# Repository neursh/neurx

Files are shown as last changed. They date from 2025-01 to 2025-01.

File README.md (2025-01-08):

# Neurx

A mechanical keyboard aiming for maximum customizability.

## Features (WIP)

- A 75% keyboard (with numpad mode can be toggled).
- 4 programmable keys + 1 knob.
- Firmware is compatible with Raspberry Pi Pico (and Pico W), written in Rust.
- Plug and play, no driver needed, with 1000Hz polling rate.
- Software for Windows, provides better control over programmable keys.

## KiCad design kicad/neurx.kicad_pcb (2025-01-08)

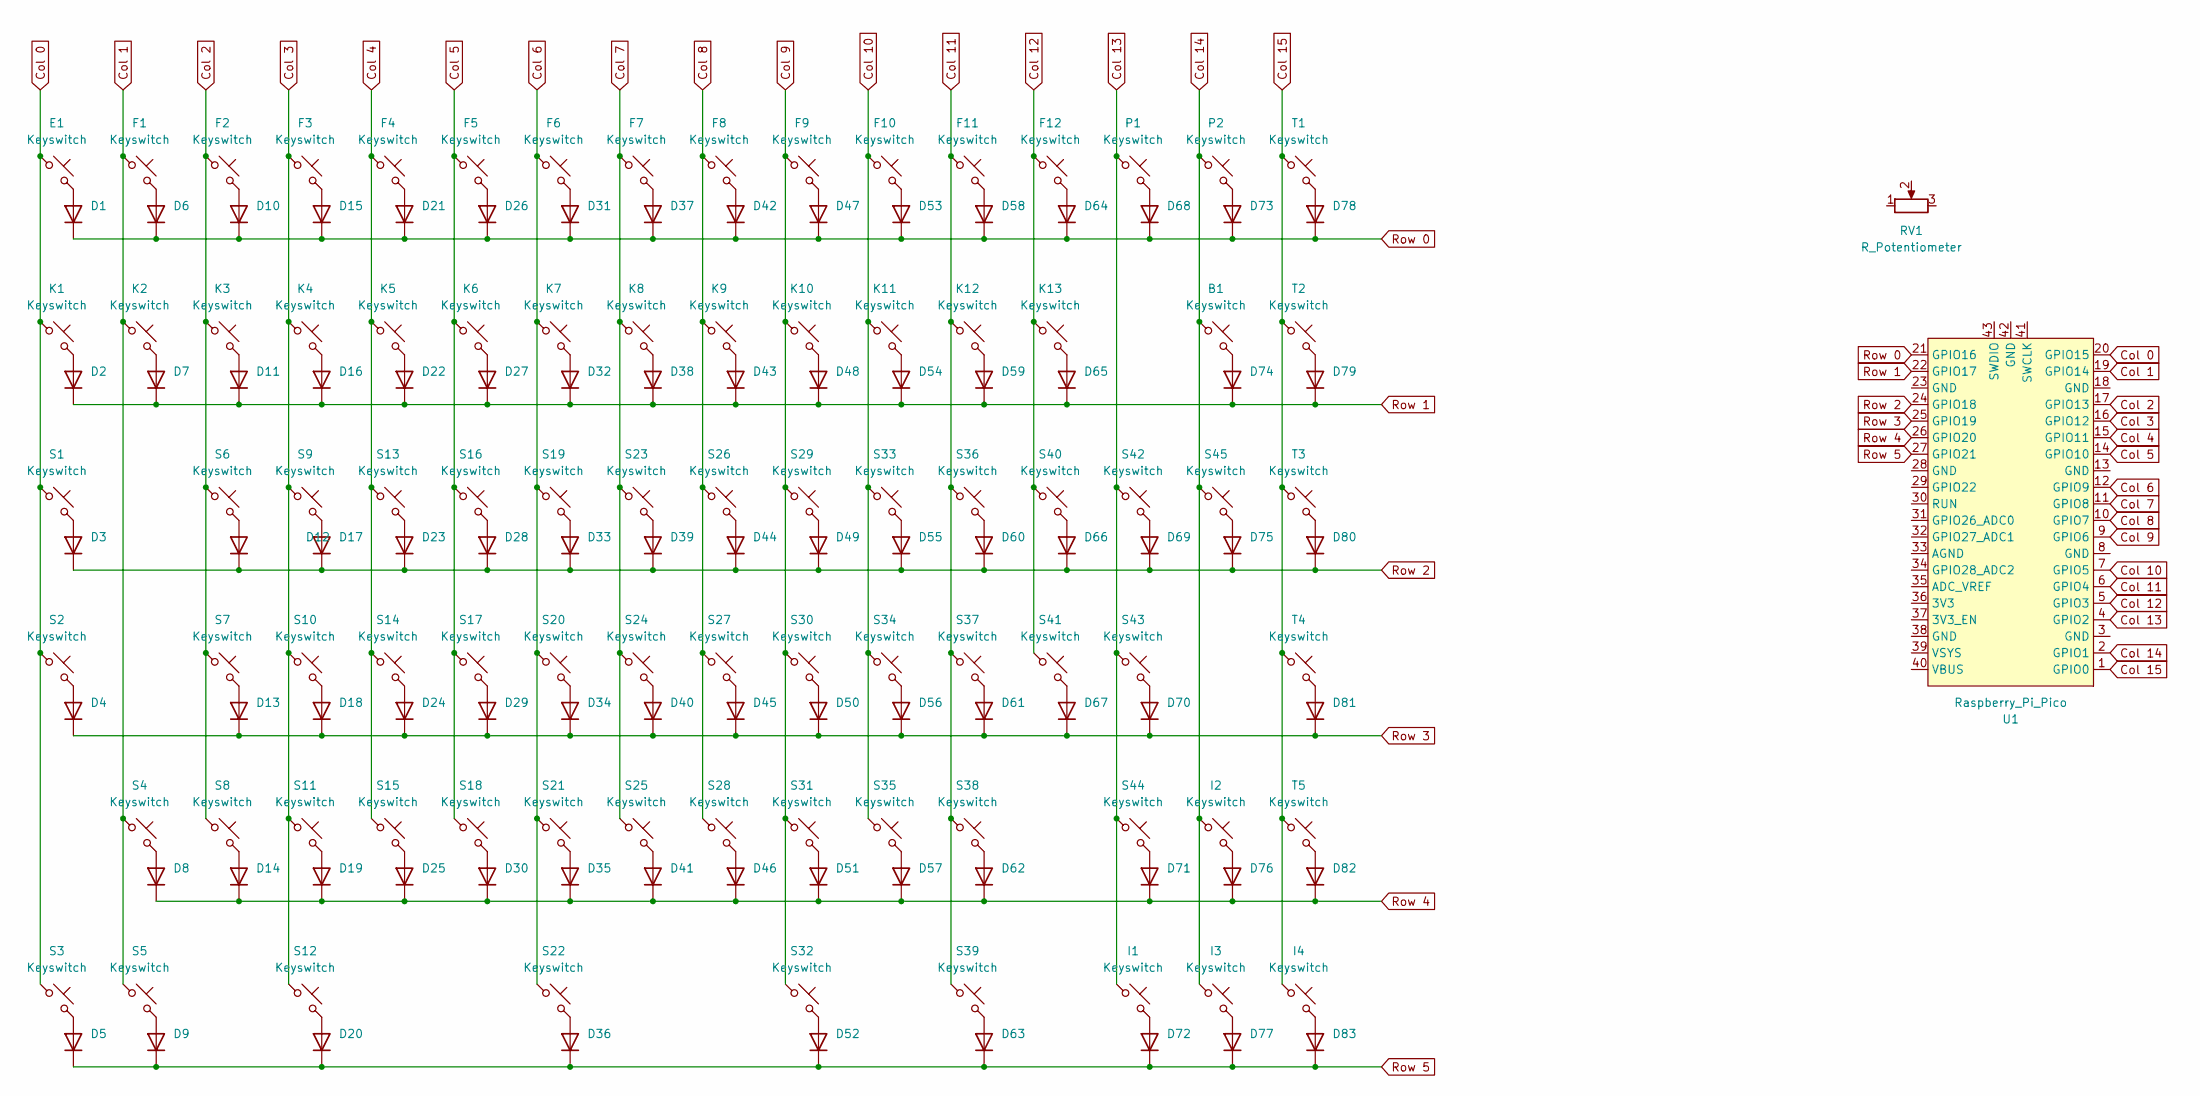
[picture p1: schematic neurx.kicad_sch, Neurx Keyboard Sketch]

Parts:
B1: Keyswitch; MX_PCB_2.00u
D1, D2, D3, D4, D5, D6, D7, D8, D9, D10, D11, D12, D13, D14, D15, D16, D17, D18, D19, D20, D21, D22, D23, D24, D25, D26, D27, D28, D29, D30, D31, D32, D33, D34, D35, D36, D37, D38, D39, D40, D41, D42, D43, D44, D45, D46, D47, D48, D49, D50, D51, D52, D53, D54, D55, D56, D57, D58, D59, D60, D61, D62, D63, D64, D65, D66, D67, D68, D69, D70, D71, D72, D73, D74, D75, D76, D77, D78, D79, D80, D81, D82, D83: Diode; Diode_DO-35
E1: Keyswitch; MX_PCB_1.00u
F1, F2, F3, F4, F5, F6, F7, F8, F9, F10, F11, F12: Keyswitch; MX_PCB_1.00u
I1, I2, I3, I4: Keyswitch; MX_PCB_1.00u
K1, K2, K3, K4, K5, K6, K7, K8, K9, K10, K11, K12, K13: Keyswitch; MX_PCB_1.00u
P1, P2: Keyswitch; MX_PCB_1.00u
RV1: R_Potentiometer
S1, S45: Keyswitch; MX_PCB_1.50u
S2, S44: Keyswitch; MX_PCB_1.75u
S3, S5, S12, S32, S39: Keyswitch; MX_PCB_1.25u
S4, S43: Keyswitch; MX_PCB_2.25u
S6, S7, S8, S9, S10, S11, S13, S14, S15, S16, S17, S18, S19, S20, S21, S23, S24, S25, S26, S27, S28, S29, S30, S31, S33, S34, S35, S36, S37, S38, S40, S41, S42: Keyswitch; MX_PCB_1.00u
S22: Keyswitch; MX_PCB_6.25u
T1, T2, T3, T4, T5: Keyswitch; MX_PCB_1.00u
U1: Raspberry_Pi_Pico

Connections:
Col 0: E1.1, K1.1, S1.1, S2.1, S3.1, U1.20 (GPIO15)
Col 1: F1.1, K2.1, S4.1, S5.1, U1.19 (GPIO14)
Col 2: F2.1, K3.1, S6.1, S7.1, S8.1, U1.17 (GPIO13)
Col 3: F3.1, K4.1, S9.1, S10.1, S11.1, S12.1, U1.16 (GPIO12)
Col 4: F4.1, K5.1, S13.1, S14.1, S15.1, U1.15 (GPIO11)
Col 5: F5.1, K6.1, S16.1, S17.1, S18.1, U1.14 (GPIO10)
Col 6: F6.1, K7.1, S19.1, S20.1, S21.1, S22.1, U1.12 (GPIO9)
Col 7: F7.1, K8.1, S23.1, S24.1, S25.1, U1.11 (GPIO8)
Col 8: F8.1, K9.1, S26.1, S27.1, S28.1, U1.10 (GPIO7)
Col 9: F9.1, K10.1, S29.1, S30.1, S31.1, S32.1, U1.9 (GPIO6)
Col 10: F10.1, K11.1, S33.1, S34.1, S35.1, U1.7 (GPIO5)
Col 11: F11.1, K12.1, S36.1, S37.1, S38.1, S39.1, U1.6 (GPIO4)
Col 12: F12.1, K13.1, S40.1, S41.1, U1.5 (GPIO3)
Col 13: I1.1, P1.1, S42.1, S43.1, S44.1, U1.4 (GPIO2)
Col 14: B1.1, I2.1, I3.1, P2.1, S45.1, U1.2 (GPIO1)
Col 15: I4.1, T1.1, T2.1, T3.1, T4.1, T5.1, U1.1 (GPIO0)
unnamed: D1.2 (A), E1.2
unnamed: D2.2 (A), K1.2
unnamed: D3.2 (A), S1.2
unnamed: D4.2 (A), S2.2
unnamed: D5.2 (A), S3.2
unnamed: D6.2 (A), F1.2
unnamed: D7.2 (A), K2.2
unnamed: D8.2 (A), S4.2
unnamed: D9.2 (A), S5.2
unnamed: D10.2 (A), F2.2
unnamed: D11.2 (A), K3.2
unnamed: D12.2 (A), S6.2
unnamed: D13.2 (A), S7.2
unnamed: D14.2 (A), S8.2
unnamed: D15.2 (A), F3.2
unnamed: D16.2 (A), K4.2
unnamed: D17.2 (A), S9.2
unnamed: D18.2 (A), S10.2
unnamed: D19.2 (A), S11.2
unnamed: D20.2 (A), S12.2
unnamed: D21.2 (A), F4.2
unnamed: D22.2 (A), K5.2
unnamed: D23.2 (A), S13.2
unnamed: D24.2 (A), S14.2
unnamed: D25.2 (A), S15.2
unnamed: D26.2 (A), F5.2
unnamed: D27.2 (A), K6.2
unnamed: D28.2 (A), S16.2
unnamed: D29.2 (A), S17.2
unnamed: D30.2 (A), S18.2
unnamed: D31.2 (A), F6.2
unnamed: D32.2 (A), K7.2
unnamed: D33.2 (A), S19.2
unnamed: D34.2 (A), S20.2
unnamed: D35.2 (A), S21.2
unnamed: D36.2 (A), S22.2
unnamed: D37.2 (A), F7.2
unnamed: D38.2 (A), K8.2
unnamed: D39.2 (A), S23.2
unnamed: D40.2 (A), S24.2
unnamed: D41.2 (A), S25.2
unnamed: D42.2 (A), F8.2
unnamed: D43.2 (A), K9.2
unnamed: D44.2 (A), S26.2
unnamed: D45.2 (A), S27.2
unnamed: D46.2 (A), S28.2
unnamed: D47.2 (A), F9.2
unnamed: D48.2 (A), K10.2
unnamed: D49.2 (A), S29.2
unnamed: D50.2 (A), S30.2
unnamed: D51.2 (A), S31.2
unnamed: D52.2 (A), S32.2
unnamed: D53.2 (A), F10.2
unnamed: D54.2 (A), K11.2
unnamed: D55.2 (A), S33.2
unnamed: D56.2 (A), S34.2
unnamed: D57.2 (A), S35.2
unnamed: D58.2 (A), F11.2
unnamed: D59.2 (A), K12.2
unnamed: D60.2 (A), S36.2
unnamed: D61.2 (A), S37.2
unnamed: D62.2 (A), S38.2
unnamed: D63.2 (A), S39.2
unnamed: D64.2 (A), F12.2
unnamed: D65.2 (A), K13.2
unnamed: D66.2 (A), S40.2
unnamed: D67.2 (A), S41.2
unnamed: D68.2 (A), P1.2
unnamed: D69.2 (A), S42.2
unnamed: D70.2 (A), S43.2
unnamed: D71.2 (A), S44.2
unnamed: D72.2 (A), I1.2
unnamed: D73.2 (A), P2.2
unnamed: B1.2, D74.2 (A)
unnamed: D75.2 (A), S45.2
unnamed: D76.2 (A), I2.2
unnamed: D77.2 (A), I3.2
unnamed: D78.2 (A), T1.2
unnamed: D79.2 (A), T2.2
unnamed: D80.2 (A), T3.2
unnamed: D81.2 (A), T4.2
unnamed: D82.2 (A), T5.2
unnamed: D83.2 (A), I4.2
Row 0: D1.1 (K), D6.1 (K), D10.1 (K), D15.1 (K), D21.1 (K), D26.1 (K), D31.1 (K), D37.1 (K), D42.1 (K), D47.1 (K), D53.1 (K), D58.1 (K), D64.1 (K), D68.1 (K), D73.1 (K), D78.1 (K), U1.21 (GPIO16)
Row 1: D2.1 (K), D7.1 (K), D11.1 (K), D16.1 (K), D22.1 (K), D27.1 (K), D32.1 (K), D38.1 (K), D43.1 (K), D48.1 (K), D54.1 (K), D59.1 (K), D65.1 (K), D74.1 (K), D79.1 (K), U1.22 (GPIO17)
Row 2: D3.1 (K), D12.1 (K), D17.1 (K), D23.1 (K), D28.1 (K), D33.1 (K), D39.1 (K), D44.1 (K), D49.1 (K), D55.1 (K), D60.1 (K), D66.1 (K), D69.1 (K), D75.1 (K), D80.1 (K), U1.24 (GPIO18)
Row 3: D4.1 (K), D13.1 (K), D18.1 (K), D24.1 (K), D29.1 (K), D34.1 (K), D40.1 (K), D45.1 (K), D50.1 (K), D56.1 (K), D61.1 (K), D67.1 (K), D70.1 (K), D81.1 (K), U1.25 (GPIO19)
Row 4: D8.1 (K), D14.1 (K), D19.1 (K), D25.1 (K), D30.1 (K), D35.1 (K), D41.1 (K), D46.1 (K), D51.1 (K), D57.1 (K), D62.1 (K), D71.1 (K), D76.1 (K), D82.1 (K), U1.26 (GPIO20)
Row 5: D5.1 (K), D9.1 (K), D20.1 (K), D36.1 (K), D52.1 (K), D63.1 (K), D72.1 (K), D77.1 (K), D83.1 (K), U1.27 (GPIO21)

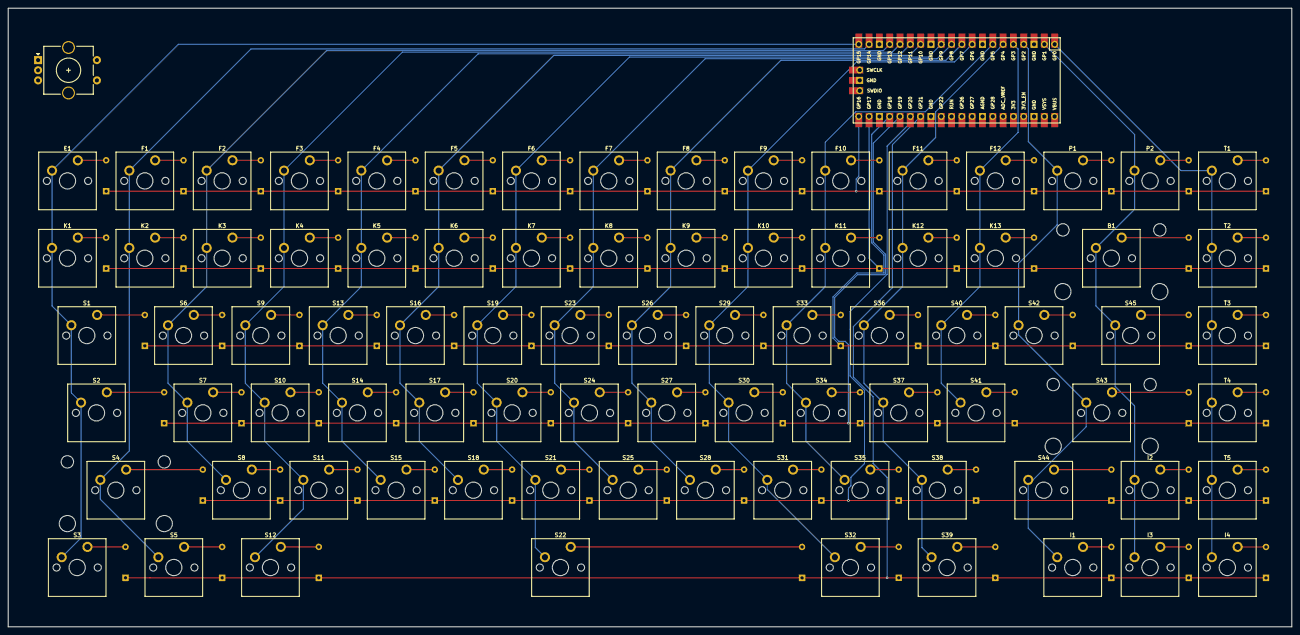
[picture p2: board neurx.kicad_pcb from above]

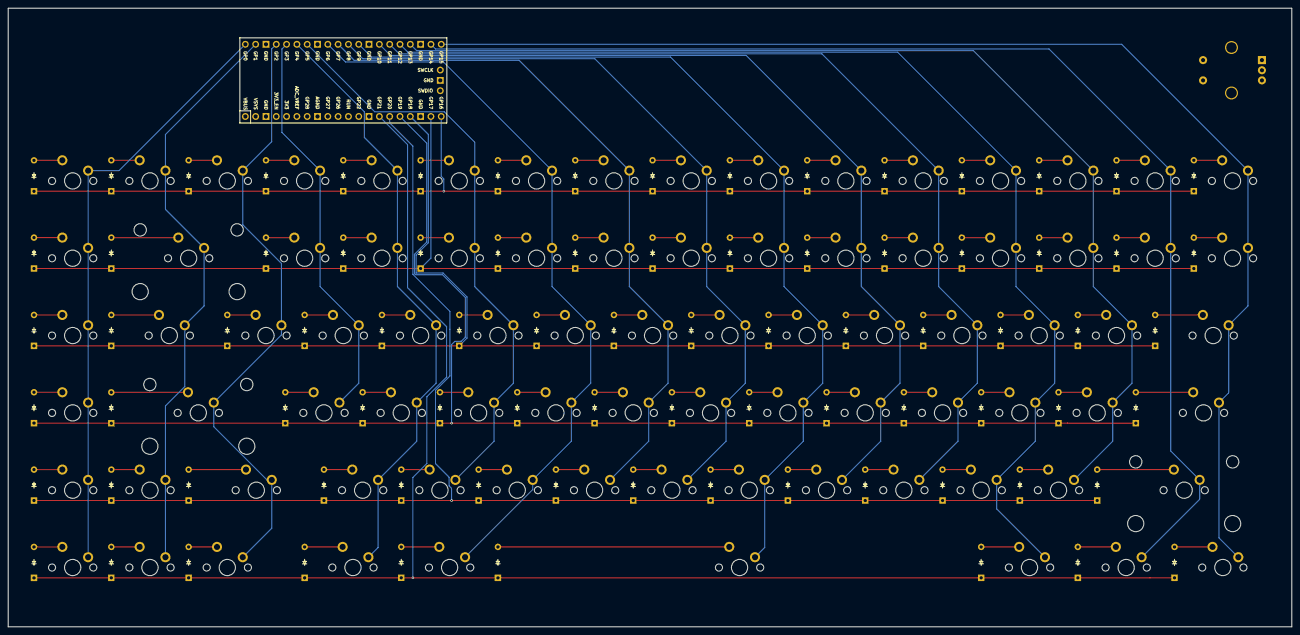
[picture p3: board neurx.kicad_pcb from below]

Board: 2 copper layers, 316.2 x 152.4 mm, 167 parts (83 on the bottom side), 105 nets.

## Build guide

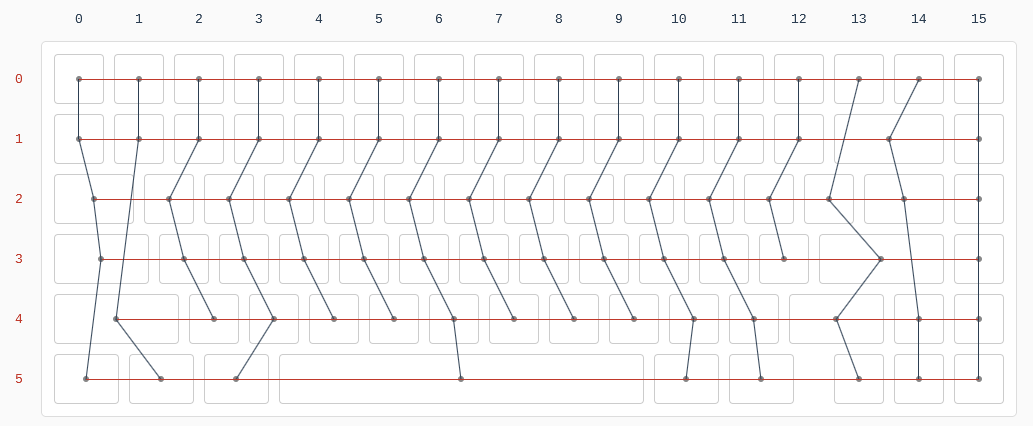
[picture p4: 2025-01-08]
wiring_ref.png

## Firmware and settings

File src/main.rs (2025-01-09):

#![no_std]
#![no_main]

mod matrix;
mod keycode;

use core::{ panic::PanicInfo, sync::atomic::{ AtomicBool, Ordering } };

use embassy_executor::Spawner;
use embassy_futures::{ join::join, yield_now };
use embassy_rp::{
    bind_interrupts,
    gpio::{ Input, Level, Output, Pull },
    peripherals::USB,
    usb::{ Driver, InterruptHandler },
};
use embassy_usb::{
    class::hid::{ HidReaderWriter, RequestHandler, State },
    Builder,
    Config,
    Handler,
};
use matrix::MatrixLayout;
use usbd_hid::descriptor::{ KeyboardReport, SerializedDescriptor };

bind_interrupts!(struct Irqs {
    USBCTRL_IRQ => InterruptHandler<USB>;
});

#[panic_handler]
fn panic(_info: &PanicInfo) -> ! {
    loop {
    }
}

#[embassy_executor::main]
async fn main(_spawner: Spawner) {
    let peripherals = embassy_rp::init(Default::default());
    let driver = Driver::new(peripherals.USB, Irqs);

    let mut matrix = MatrixLayout::new(
        [
            Output::new(peripherals.PIN_15, Level::Low),
            Output::new(peripherals.PIN_14, Level::Low),
            Output::new(peripherals.PIN_13, Level::Low),
            Output::new(peripherals.PIN_12, Level::Low),
            Output::new(peripherals.PIN_11, Level::Low),
            Output::new(peripherals.PIN_10, Level::Low),
            Output::new(peripherals.PIN_9, Level::Low),
            Output::new(peripherals.PIN_8, Level::Low),
            Output::new(peripherals.PIN_7, Level::Low),
            Output::new(peripherals.PIN_6, Level::Low),
            Output::new(peripherals.PIN_5, Level::Low),
            Output::new(peripherals.PIN_4, Level::Low),
            Output::new(peripherals.PIN_3, Level::Low),
            Output::new(peripherals.PIN_2, Level::Low),
            Output::new(peripherals.PIN_1, Level::Low),
            Output::new(peripherals.PIN_0, Level::Low),
        ],
        [
            Input::new(peripherals.PIN_16, Pull::Down),
            Input::new(peripherals.PIN_17, Pull::Down),
            Input::new(peripherals.PIN_18, Pull::Down),
            Input::new(peripherals.PIN_19, Pull::Down),
            Input::new(peripherals.PIN_20, Pull::Down),
            Input::new(peripherals.PIN_21, Pull::Down),
        ]
    );

    let mut config = Config::new(14521, 1819);
    config.manufacturer = Some("Neurs");
    config.product = Some("Neurx");
    config.serial_number = Some("Neurx 1.0");
    config.max_power = 100;
    config.max_packet_size_0 = 64;

    let mut config_descriptor = [0; 256];
    let mut bos_descriptor = [0; 256];
    let mut msos_descriptor = [0; 256];
    let mut control_buf = [0; 64];
    let mut request_handler = NeurxRequestHandler {};
    let mut device_handler = DeviceHandler::new();

    let mut state = State::new();

    let mut builder = Builder::new(
        driver,
        config,
        &mut config_descriptor,
        &mut bos_descriptor,
        &mut msos_descriptor,
        &mut control_buf
    );

    builder.handler(&mut device_handler);

    // Create classes on the builder.
    let config = embassy_usb::class::hid::Config {
        report_descriptor: KeyboardReport::desc(),
        request_handler: None,
        poll_ms: 1,
        max_packet_size: 64,
    };
    let hid = HidReaderWriter::<_, 1, 8>::new(&mut builder, &mut state, config);

    let mut usb = builder.build();
    let runtime = usb.run();

    let (reader, mut writer) = hid.split();

    let usb_output = async {
        loop {
            let report = matrix.scan();
            writer.write(report).await.ok();

            yield_now().await;
        }
    };

    let host_request = async {
        reader.run(false, &mut request_handler).await;
    };

    join(runtime, join(usb_output, host_request)).await;
}

struct NeurxRequestHandler {}
impl RequestHandler for NeurxRequestHandler {}

struct DeviceHandler {
    configured: AtomicBool,
}
impl DeviceHandler {
    fn new() -> Self {
        DeviceHandler {
            configured: AtomicBool::new(false),
        }
    }
}

impl Handler for DeviceHandler {
    fn enabled(&mut self, _enabled: bool) {
        self.configured.store(false, Ordering::Relaxed);
    }

    fn reset(&mut self) {
        self.configured.store(false, Ordering::Relaxed);
    }

    fn addressed(&mut self, _addr: u8) {
        self.configured.store(false, Ordering::Relaxed);
    }

    fn configured(&mut self, configured: bool) {
        self.configured.store(configured, Ordering::Relaxed);
    }
}

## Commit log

2025-01-07 Add prettier and heapless to replace some std structures
    [main.rs]
2025-01-08 Plug row 5 to pico, completely forgot that
    [neurx.kicad_sch]
2025-01-08 Update design from sketch
    [neurx.kicad_pcb]
2025-01-08 Provide the struct with columns and rows to avoid ownership problems, finish implementation
    [main.rs]
2025-01-09 Report using reference, avoid creating a new array for each scan.
    [main.rs]
